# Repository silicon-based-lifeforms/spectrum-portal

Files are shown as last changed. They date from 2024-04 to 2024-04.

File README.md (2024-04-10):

# spectrum portal

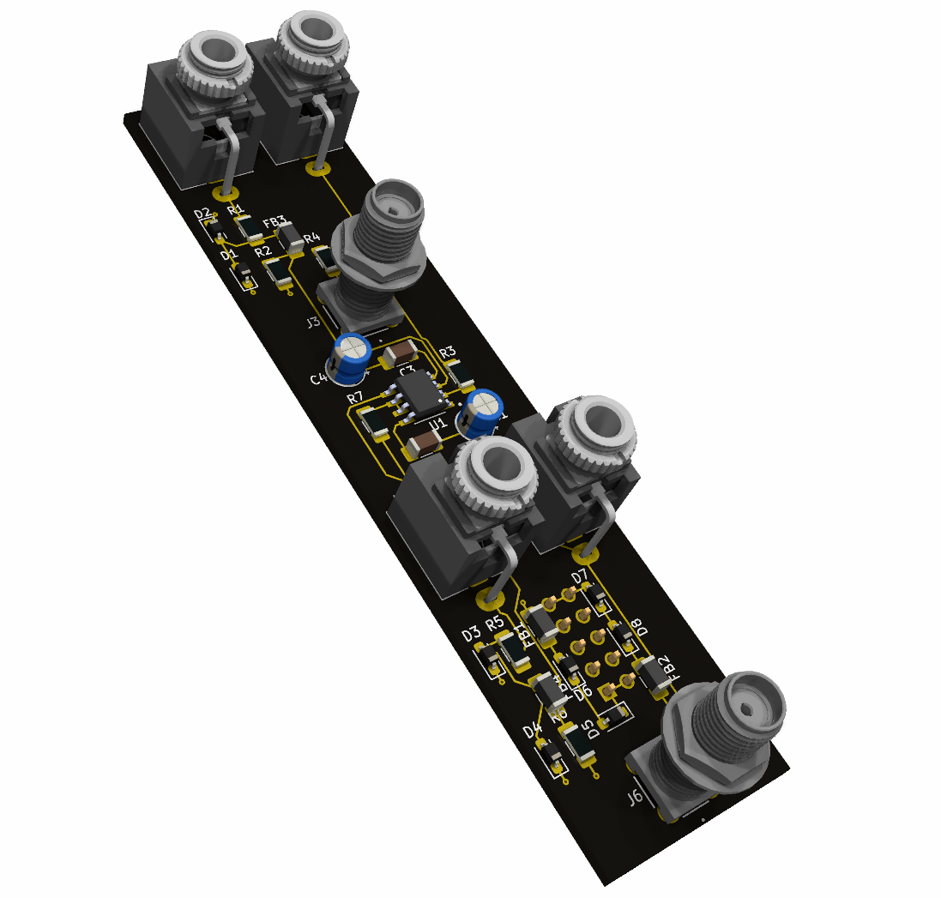
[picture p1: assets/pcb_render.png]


## about
Spectrum Portal is a **work-in-progress** open-hardware Eurorack module for interfacing with an oscilloscope, spectrum analyzer, frequency counter, or other device of interest. 

## features
- Connect up to two Eurorack signals to two dedicated SMA outputs (and then hook up to your scope with a BNC-SMA adapter)
- Keep a copy of your signals using a built-in buffered multiple, one for each of the two inputs.
- A whole butt ton of circuit protection mechanisms with many pairs of belts and suspenders.

## motivations
- Seeing and studying the waveforms you're creating is a fantastic tool for exploring synthesis. It's a really exciting thing to see, and it really enhances my modular experience. 
- Modules with a built in Oscilloscope are pretty cool. But I already have a dedicated Oscilloscope that would fit the bit really nicely, plus I'd love to be able to hookup a modular to an analog CRT scope for the coolness factor.
- I'm fascinated by oscilloscope art and am excited by the possibilities of creating oscilloscope art with a modular synth.
- I wanted something more robust than a passive adapter/cable, that lived inside the rack as a dedicated module. 
- I just want to design and build eurorack modules.
- I want to further the proliferation of open-hardware eurorack modules across the galaxy

## design goals
- Open-hardware
- Must be fully user-servicable and user-buildable (big SMD components that are easy to hand-solder are fine, tiny packages that require specialized equipment is not fine)
- Strike a good compromise between features, quality, size and cost. Quality comes at the expense of added cost, features come at the expense of added size (and added cost).

## contributing
Contributions are heavily encouraged! There are many areas where the design can be significantly improved (it's still a work-in-progress, afterall).

## licensing
- The hardware is licensed under the strongly reciprocal variant of the [CERN Open Hardware License](https://ohwr.org/project/cernohl/wikis/Documents/CERN-OHL-version-2) (specifically CERN-OHL-S).
- There's no source code for this module, it's a pure hardware affair. But any future modules that have firmware will have that firmware licensed under the GNU GPL v3.
- There's no documentation (yet), but any future documentation will be licensed under an appropriate open-source license.

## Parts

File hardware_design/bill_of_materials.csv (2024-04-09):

Reference | Qty | Description | DIGIKEY_PART
U1 | 1 | TL072 DIP-8/SOIC-8 | 296-7194-1-ND
R4,R8 | 2 | 1/4W Thin-Film Resistor, 1% Tolerance | 311-47.0FRCT-ND
R3,R7 | 2 | 1/4W Thin-Film Resistor, 1% Tolerance | 311-100FRCT-ND
R2,R6 | 2 | 1/4W Thin-Film Resistor, 1% Tolerance | 311-100KFRCT-ND
R1,R5 | 2 | 1/4W Thin-Film Resistor, 1% Tolerance | 311-1.00KFRCT-ND
J7 | 1 | 10 Position 2x5 Shrouded IDC Header, 2.54MM pitch | SBH11-PBPC-D05-ST-BK
J3,J6 | 2 | SMA-F bulkhead connector | ACX1976-ND
J1,J2,J4,J5 | 4 | Thonkiconn 3.5mm Jack (PJ398SM) | NOT DIGIKEY PRODUCT
FB1,FB2,FB3,FB4 | 4 | Ferrite bead | 1934-1489-1-ND
D6,D8 | 2 | Transient Voltage Suppression diode | D12V0H1U2WS-7DICT-ND
D5,D7 | 2 | Schottky diode | NSR0530HT1GOSCT-ND
D1,D2,D3,D4 | 4 | Transient Voltage Suppression diode | 3757-PJGBLC15C_R1_00001CT-ND
C2,C3 | 2 | Unpolarized ceramic capacitor | 4713-GMT31X5R106K50NT2CT-ND
C1,C4 | 2 | Polarized aluminum electrolytic capacitor | P14488-ND

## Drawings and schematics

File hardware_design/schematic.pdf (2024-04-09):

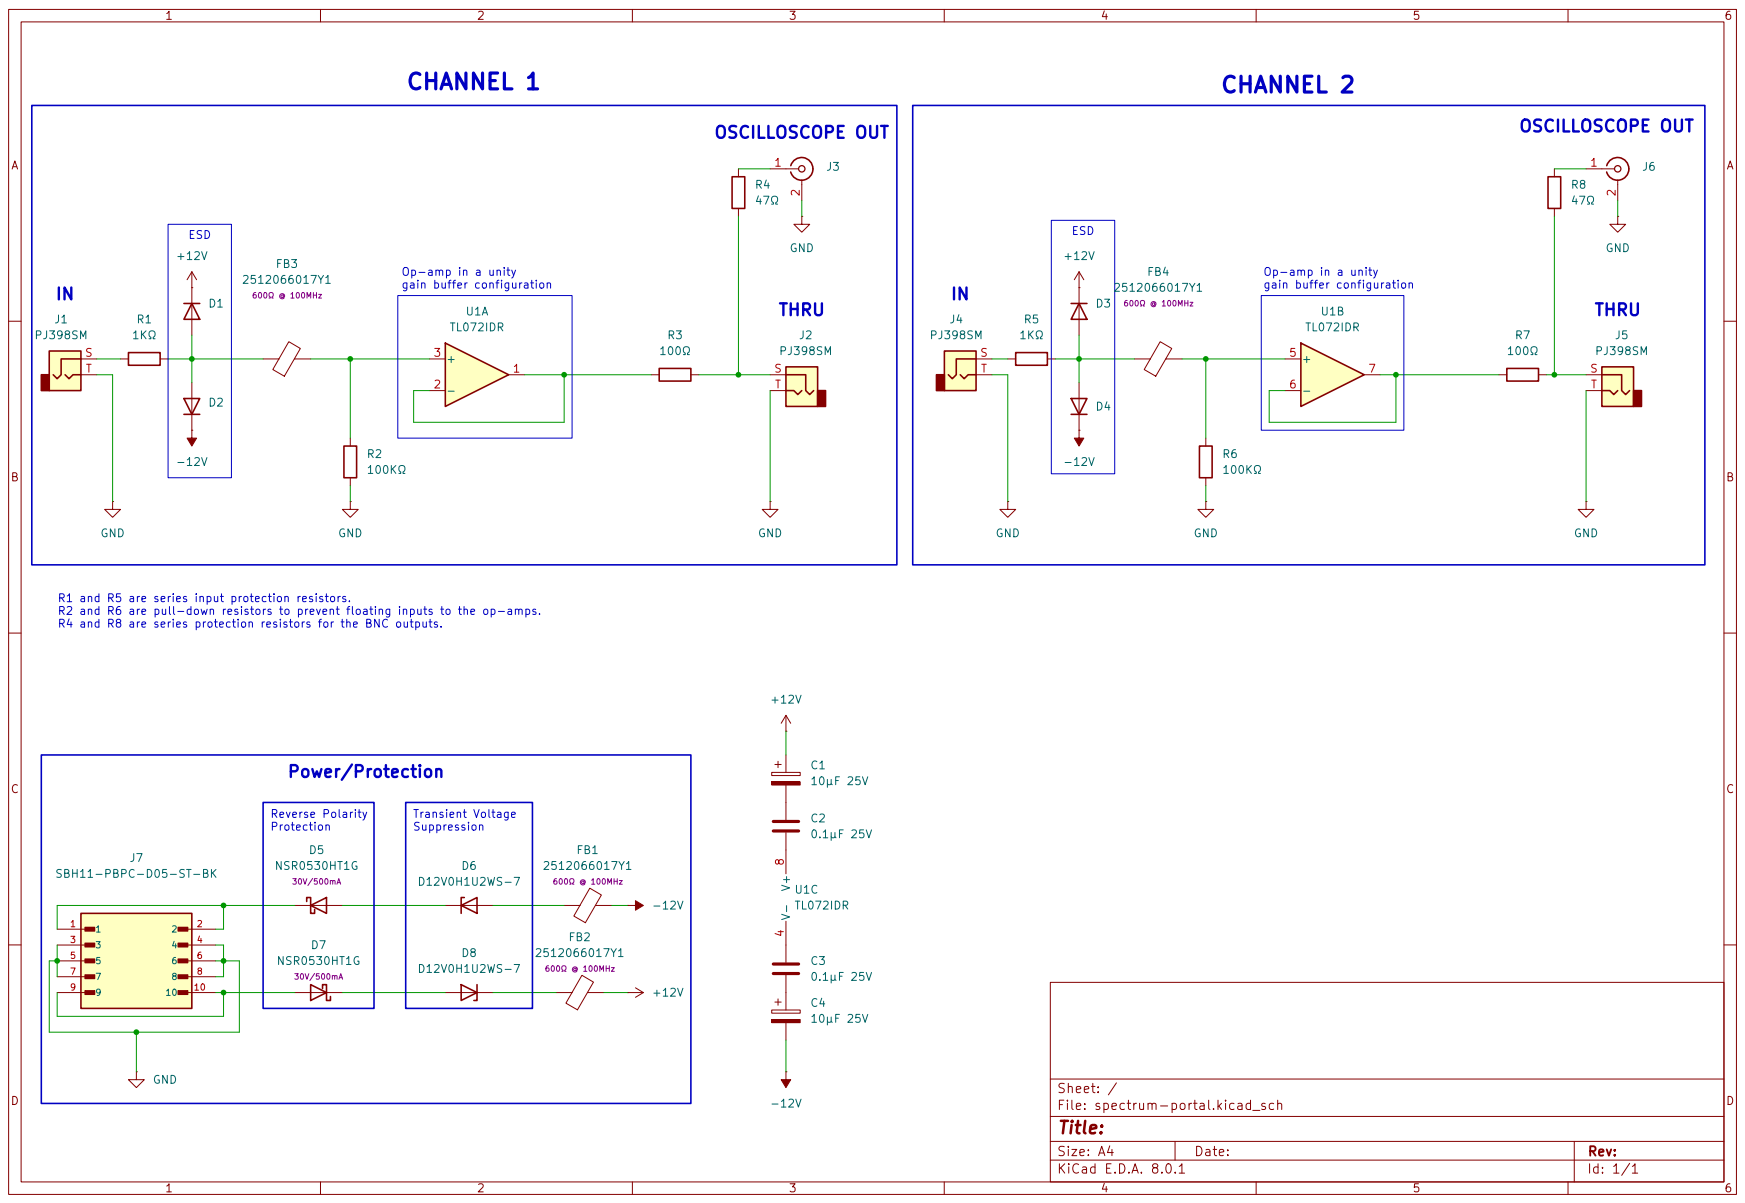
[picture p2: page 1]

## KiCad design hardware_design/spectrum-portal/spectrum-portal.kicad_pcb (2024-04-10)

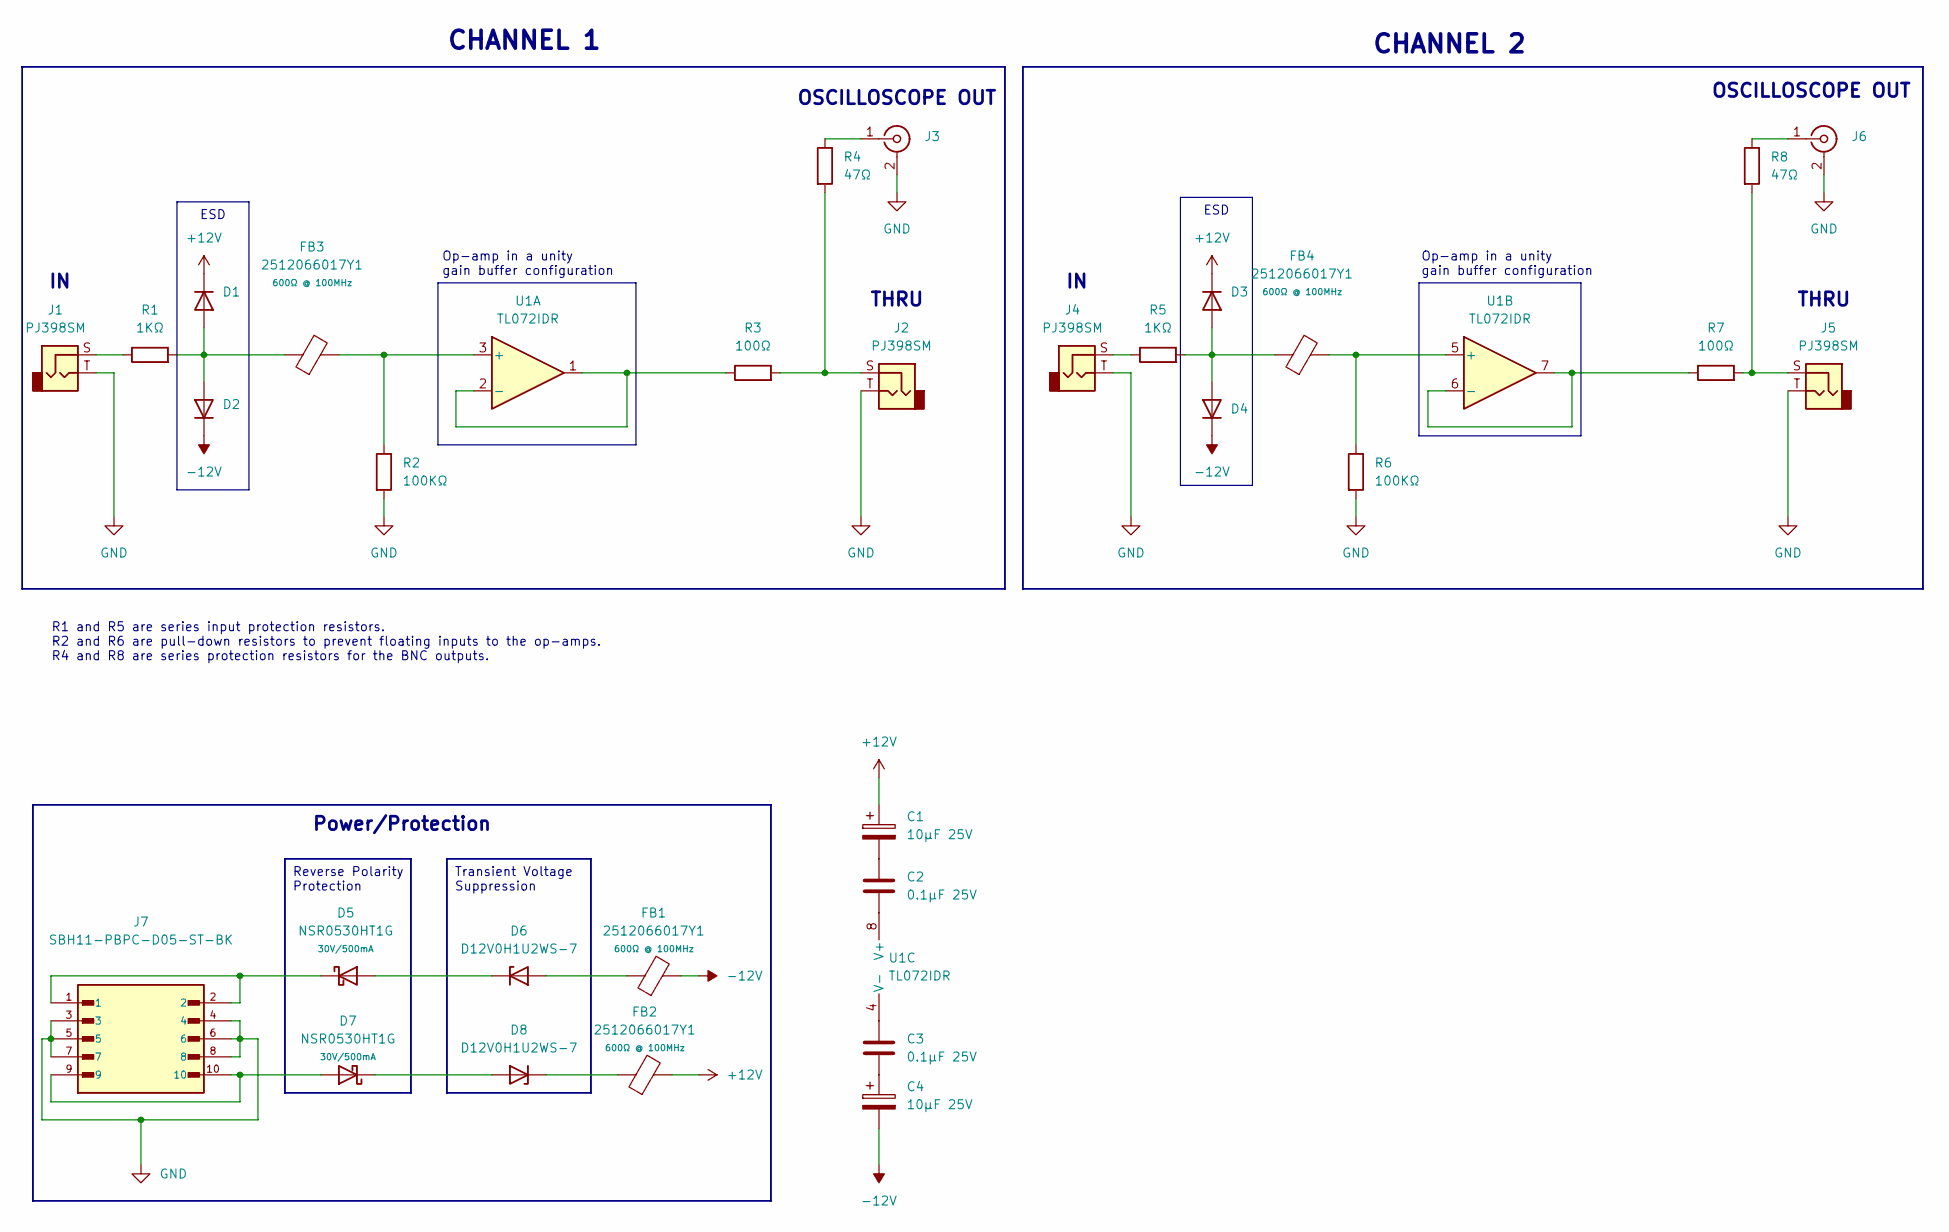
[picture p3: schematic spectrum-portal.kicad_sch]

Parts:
C1, C4: 10µF 25V; CP_Radial_D4.0mm_P1.50mm; DIGIKEY_PART P14488-ND
C2, C3: 0.1µF 25V; C_1206_3216Metric_Pad1.33x1.80mm_HandSolder; DIGIKEY_PART 4713-GMT31X5R106K50NT2CT-ND
D1, D2, D3, D4: PJGBLC15C_R1_00001; D_SOD-323_HandSoldering; DIGIKEY_PART 3757-PJGBLC15C_R1_00001CT-ND
D5, D7: NSR0530HT1G; D_SOD-323_HandSoldering; Rating 30V/500mA; DIGIKEY_PART NSR0530HT1GOSCT-ND
D6, D8: D12V0H1U2WS-7; D_SOD-323_HandSoldering; DIGIKEY_PART D12V0H1U2WS-7DICT-ND
FB1, FB2, FB3, FB4: 2512066017Y1; L_1206_3216Metric_Pad1.42x1.75mm_HandSolder; Rating 600Ω @ 100MHz; DIGIKEY_PART 1934-1489-1-ND
J1, J2, J4, J5: PJ398SM; Jack_3.5mm_QingPu_WQP-PJ398SM_Vertical; DIGIKEY_PART NOT DIGIKEY PRODUCT
J3, J6: CONN_132291_AMP; DIGIKEY_PART ACX1976-ND
J7: SBH11-PBPC-D05-ST-BK; SULLINS_SBH11-PBPC-D05-ST-BK; DIGIKEY_PART SBH11-PBPC-D05-ST-BK
R1, R5: 1KΩ; R_1206_3216Metric_Pad1.30x1.75mm_HandSolder; DIGIKEY_PART 311-1.00KFRCT-ND
R2, R6: 100KΩ; R_1206_3216Metric_Pad1.30x1.75mm_HandSolder; DIGIKEY_PART 311-100KFRCT-ND
R3, R7: 100Ω; R_1206_3216Metric_Pad1.30x1.75mm_HandSolder; DIGIKEY_PART 311-100FRCT-ND
R4: 47Ω; R_1206_3216Metric_Pad1.30x1.75mm_HandSolder; Rating 1% 1/4W; DIGIKEY_PART 311-47.0FRCT-ND
R8: 47Ω; R_1206_3216Metric_Pad1.30x1.75mm_HandSolder; DIGIKEY_PART 311-47.0FRCT-ND
U1: TL072IDR; SOIC127P599X175-8N; DIGIKEY_PART 296-7194-1-ND

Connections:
+12V: C1.1, D1.1 (K), D3.1 (K), FB2.2
-12V: C4.2, D2.1 (K), D4.1 (K), FB1.2
GND: J1.T, J2.T, J3.2 (Ext), J4.T, J5.T, J6.2 (Ext), J7.3, J7.4, J7.5, J7.6, J7.7, J7.8, R2.2, R6.2
unnamed: C1.2, C2.1
unnamed: C3.2, C4.1
unnamed: D1.2 (A), D2.2 (A), FB3.1, R1.2
unnamed: D3.2 (A), D4.2 (A), FB4.1, R5.2
unnamed: D5.2 (A), D6.1 (K)
unnamed: D5.1 (K), J7.1, J7.2
unnamed: D6.2 (A), FB1.1
unnamed: D7.2 (A), J7.9, J7.10
unnamed: D7.1 (K), D8.2 (A)
unnamed: D8.1 (K), FB2.1
unnamed: J1.S, R1.1
unnamed: J2.S, R3.2, R4.2
unnamed: J3.1 (In), R4.1
unnamed: J4.S, R5.1
unnamed: J5.S, R7.2, R8.2
unnamed: J6.1 (In), R8.1
unnamed: FB3.2, R2.1, U1.3 (+)
unnamed: R3.1, U1.1, U1.2 (-)
unnamed: FB4.2, R6.1, U1.5 (+)
unnamed: R7.1, U1.6 (-), U1.7
unnamed: C2.2, U1.8 (V+)
unnamed: C3.1, U1.4 (V-)

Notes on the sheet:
Transient Voltage Suppression
Power/Protection
ESD
Reverse Polarity Protection
OSCILLOSCOPE OUT
R1 and R5 are series input protection resistors. R2 and R6 are pull-down resistors to prevent floating inputs to the op-amps. R4 and R8 are series protection resistors for the BNC outputs.
THRU
CHANNEL 1
Op-amp in a unity gain buffer configuration
CHANNEL 2

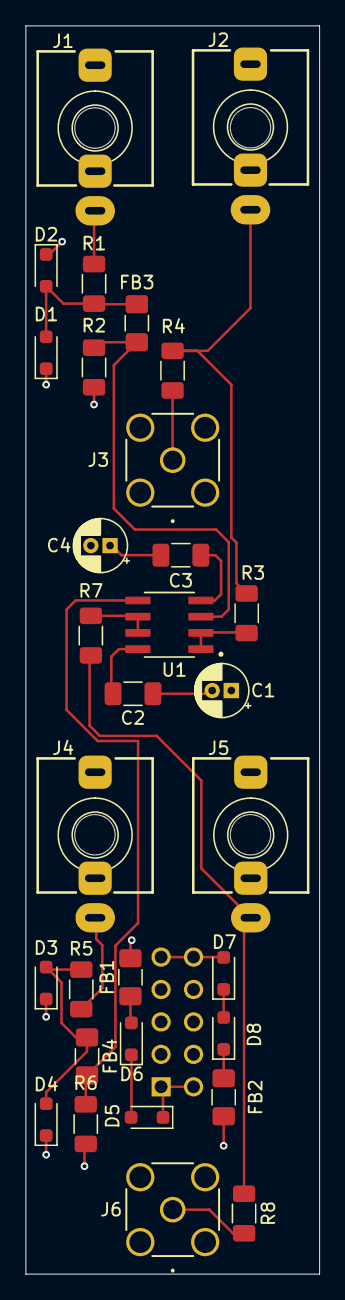
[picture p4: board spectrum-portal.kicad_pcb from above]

Board: 4 copper layers, 23.0 x 97.8 mm, 32 parts (1 on the bottom side), 25 nets.

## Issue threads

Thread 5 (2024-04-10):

[5HP] Multiple issues with current circuit design

ranguli, 2024-04-10:
The 5HP version needs the following addressed:

- TVS diode placement checked and corrected
- Polarity of D2 and D4 fixed
- Op-amp power wiring fixed
- Input jack wiring corrected
- Update input jacks to correct schematic symbol (`AudioJack2_SwitchT`)
- Rotate SMD components 90 degrees to make hand-soldering easier

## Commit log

2024-04-08 WIP 4HP design
    [spectrum-portal.kicad_pcb, spectrum-portal.kicad_sch]
2024-04-09 Redesigned as 5HP, added protection components
    [spectrum-portal.kicad_pcb, spectrum-portal.kicad_sch]
2024-04-09 Switch to more affordable SMA connector
    [spectrum-portal.kicad_pcb, spectrum-portal.kicad_sch]
2024-04-09 Add render of PCB for README file
2024-04-09 Update bill of materials, add .pdf of schematic
    [bill_of_materials.csv]
2024-04-10 Fix SMA connector
    [spectrum-portal.kicad_pcb]
2024-04-10 Add exclusions for silkscreen over copper violations
